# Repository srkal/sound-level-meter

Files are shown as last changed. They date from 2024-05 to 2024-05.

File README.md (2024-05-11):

# sound-level-meter
Sound level meter for workplace with additional features

## Basic Features
* continuous measure of the sound level, use standard decibel scale
* average values from last measures
* display warning when configured level is exceeded
* support IR remote controler for configuration and mode change
* powered by standard type A USB adapter 5V 2A

## Additional Features
* display settings (brightness, rotation, mode) and noise limit are stored to non-volatile flash memory, persist after reboot or power loss
* wifi-manager supported, when connection to last wifi settings fails, switch to Access Point mode and provide interactive web page settings on 192.168.4.1
* automatic time synchronization using Network Time Protocol with correct STD/DST time shifting for central Europe
* periodical check of new firmware versions from server and automatic download and OTA update when found
* when the configured noise level is exceeded, call Google Web-app with current average, chip id, firmware version and local time - will write log entry in Google Sheet

## Used hardware parts
* ESP32 WROOM development module with basic 4MB Flash, without additional PSRAM
* digital MEMS microphone module INMP441 with I2S Interface
* Flexible Led Panel WS2812B RGB matrix 8x8 pixels
* IR receiver VS1838B
* IR Remote Control BN59
* Self locking switch button 8.5 x 8.5 mm (power-on/off)
* Single row pin header strip (module sockets)
* 2 wire red-black cable 20AWG (power supply line)
* Universal double sided PCB board 8x6 cm
* Universal double sided PCB board 8x2 cm
* 6 pin IC socket (for microphone module)
* Type A Male USB 4 Pin Plug Socket Connector With Black Plastic Cover (power supply line)
* Steel Small Phillips Flat Cross Round Head Self-tapping Screw M2
* 10 pin flat color ribbon cable
* Resistor 330 Ohm 0.5W
* Aluminum Electrolytic Capacitor 330uF 6.3V

## Construction
* 3D printed case, base + lid connected together using presision snap joins (open scad files in resources directory)
* hole for power supply line
* PCBs mounted on 3d printed standoffs using screws
* PCBs electrically connected together using flat ribbon cable, soldered, no connectors
* small PCB contains sensors (microphone, IR) and power switch, peeks out through case holes
* large PCB contains microcontroller and other modules
* translucent window made from two layers of transparent foils and lawyer of white paper between foils
* led panel is fixed behind window with hotglue and connected with PCB using 3 pin wire with connector

## Schematics
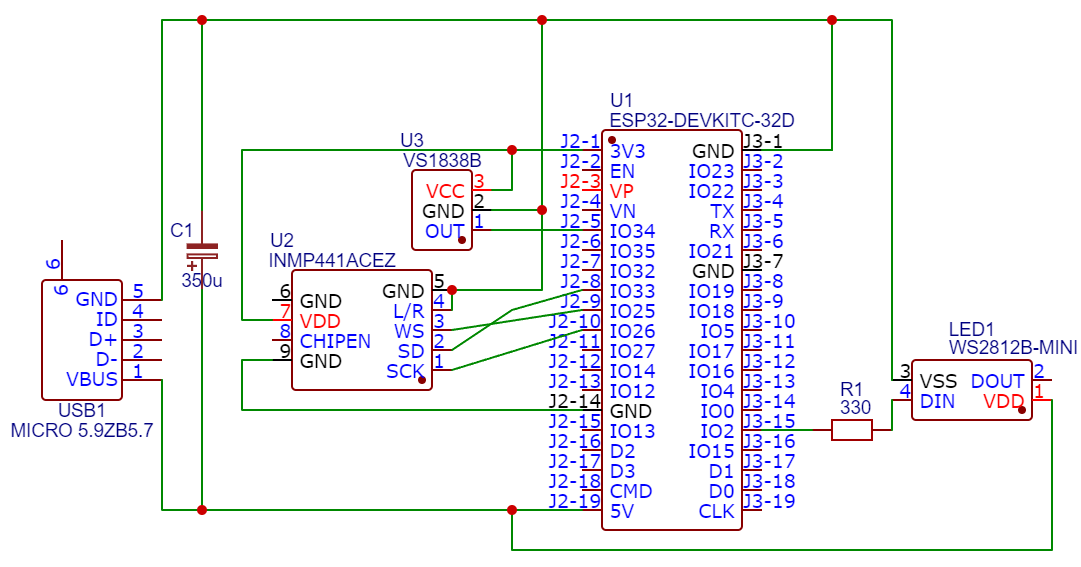
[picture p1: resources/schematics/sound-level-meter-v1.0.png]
schematics


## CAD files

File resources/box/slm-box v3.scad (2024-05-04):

//-----------------------------------------------------------------------
// Yet Another Parameterized Projectbox generator
//
//  This is a box for <template>
//
//  Version 3.0.1 (2024-01-15)
//
// This design is parameterized based on the size of a PCB.
//
// For many/complex cutoutGrills, you might need to adjust
//  the max number of elements in OpenSCAD:
//
//      Preferences->Advanced->Turn off rendering at 250000 elements
//                                                   ^^^^^^
//
//-----------------------------------------------------------------------

include <./YAPPgenerator_v3.scad>

//---------------------------------------------------------
// This design is parameterized based on the size of a PCB.
//---------------------------------------------------------
// Note: length/lengte refers to X axis, 
//       width/breedte refers to Y axis,
//       height/hoogte refers to Z axis

/*
      padding-back|<------pcb length --->|<padding-front
                            RIGHT
        0    X-axis ---> 
        +----------------------------------------+   ---
        |                                        |    ^
        |                                        |   padding-right 
      Y |                                        |    v
      | |    -5,y +----------------------+       |   ---              
 B    a |         | 0,y              x,y |       |     ^              F
 A    x |         |                      |       |     |              R
 C    i |         |                      |       |     | pcb width    O
 K    s |         |                      |       |     |              N
        |         | 0,0              x,0 |       |     v              T
      ^ |    -5,0 +----------------------+       |   ---
      | |                                        |    padding-left
      0 +----------------------------------------+   ---
        0    X-as --->
                          LEFT
*/


//-- which part(s) do you want to print?
printBaseShell        = true;
printLidShell         = true;
printSwitchExtenders  = false;


// ********************************************************************
// The Following will be used as the first element in the pbc array

//Defined here so you can define the "Main" PCB using these if wanted
pcbLength           = 80; // front to back (X axis)
pcbWidth            = 60; // side to side (Y axis)
pcbThickness        = 1.6; 
standoffHeight      = 8.0; //-- How much the PCB needs to be raised from the base to leave room for solderings and whatnot
standoffDiameter    = 7.5;
standoffPinDiameter = 1.7;
standoffHoleSlack   = 0.4;

//===================================================================
// *** PCBs ***
// Printed Circuit Boards
//-------------------------------------------------------------------
//  Default origin =  yappCoordPCB : yappCoordBoxInside[0,0,0]
//
//  Parameters:
//   Required:
//    p(0) = name
//    p(1) = length
//    p(2) = width
//    p(3) = posx
//    p(4) = posy
//    p(5) = Thickness
//    p(6) = standoff_Height
//    p(7) = standoff_Diameter
//    p(8) = standoff_PinDiameter
//   Optional:
//    p(9) = standoff_HoleSlack (default to 0.4)

//The following can be used to get PCB values elsewhere in the script - not in pcb definition. 
//If "PCB Name" is omitted then "Main" is used
//  pcbLength           --> pcbLength("PCB Name")
//  pcbWidth            --> pcbWidth("PCB Name")
//  pcbThickness        --> pcbThickness("PCB Name") 
//  standoffHeight      --> standoffHeight("PCB Name") 
//  standoffDiameter    --> standoffDiameter("PCB Name") 
//  standoffPinDiameter --> standoffPinDiameter("PCB Name") 
//  standoffHoleSlack   --> standoffHoleSlack("PCB Name") 

pcb = 
[
  // Default Main PCB - DO NOT REMOVE the "Main" line.
  ["Main",              pcbLength,pcbWidth,    0,0,    pcbThickness,  standoffHeight, standoffDiameter, standoffPinDiameter, standoffHoleSlack],
    ["Sensors",         80,20,    0,pcbWidth+30,    pcbThickness,  53, standoffDiameter, 2.0, standoffHoleSlack]
];

//-------------------------------------------------------------------                            
//-- padding between pcb and inside wall
paddingFront        = 5;
paddingBack         = 5;
paddingRight        = 5;
paddingLeft         = 5;

//-- Edit these parameters for your own box dimensions
wallThickness       = 3.0;
basePlaneThickness  = 2.0;
lidPlaneThickness   = 2.0;

//-- Total height of box = lidPlaneThickness 
//                       + lidWallHeight 
//--                     + baseWallHeight 
//                       + basePlaneThickness
//-- space between pcb and lidPlane :=
//--      (bottonWallHeight+lidWallHeight) - (standoffHeight+pcbThickness)
baseWallHeight      = 32;
lidWallHeight       = 10;

//-- ridge where base and lid off box can overlap
//-- Make sure this isn't less than lidWallHeight
ridgeHeight         = 6.0;
ridgeSlack          = 0.2;
roundRadius         = 2.0;


// Set the layer height of your printer
printerLayerHeight  = 0.2;


//---------------------------
//--     C O N T R O L     --
//---------------------------
// -- Render --
renderQuality             = 8;          //-> from 1 to 32, Default = 8

// --Preview --
previewQuality            = 5;          //-> from 1 to 32, Default = 5
showSideBySide            = true;       //-> Default = true
onLidGap                  = 0;  // tip don't override to animate the lid opening
colorLid                  = "YellowGreen";   
alphaLid                  = 1;
colorBase                 = "BurlyWood";
alphaBase                 = 1;
hideLidWalls              = true;      //-> Remove the walls from the lid : only if preview and showSideBySide=true 
hideBaseWalls             = false;      //-> Remove the walls from the base : only if preview and showSideBySide=true  
showOrientation           = false;       //-> Show the Front/Back/Left/Right labels : only in preview
showPCB                   = false;      //-> Show the PCB in red : only in preview 
showSwitches              = false;      //-> Show the switches (for pushbuttons) : only in preview 
showButtonsDepressed      = false;      //-> Should the buttons in the Lid On view be in the pressed position
showOriginCoordBox        = false;      //-> Shows red bars representing the origin for yappCoordBox : only in preview 
showOriginCoordBoxInside  = false;      //-> Shows blue bars representing the origin for yappCoordBoxInside : only in preview 
showOriginCoordPCB        = false;      //-> Shows blue bars representing the origin for yappCoordBoxInside : only in preview 
showMarkersPCB            = false;      //-> Shows black bars corners of the PCB : only in preview 
showMarkersCenter         = false;      //-> Shows magenta bars along the centers of all faces  
inspectX                  = 0;          //-> 0=none (>0 from Back)
inspectY                  = 0;          //-> 0=none (>0 from Right)
inspectZ                  = 0;          //-> 0=none (>0 from Bottom)
inspectXfromBack          = true;       //-> View from the inspection cut foreward
inspectYfromLeft          = true;       //-> View from the inspection cut to the right
inspectZfromBottom        = true;       //-> View from the inspection cut up
//---------------------------
//--     C O N T R O L     --
//---------------------------

//-------------------------------------------------------------------
//-------------------------------------------------------------------
// Start of Debugging config (used if not overridden in template)
// ------------------------------------------------------------------
// ------------------------------------------------------------------

//==================================================================
//  *** Shapes ***
//------------------------------------------------------------------
//  There are a view pre defines shapes and masks
//  shapes:
//      shapeIsoTriangle, shapeHexagon, shape6ptStar
//
//  masks:
//      maskHoneycomb, maskHexCircles, maskBars, maskOffsetBars
//
//------------------------------------------------------------------
// Shapes should be defined to fit into a 1x1 box (+/-0.5 in X and Y) - they will 
// be scaled as needed.
// defined as a vector of [x,y] vertices pairs.(min 3 vertices)
// for example a triangle could be [yappPolygonDef,[[-0.5,-0.5],[0,0.5],[0.5,-0.5]]];
// To see how to add your own shapes and mask see the YAPPgenerator program
//------------------------------------------------------------------


// Show sample of a Mask
//SampleMask(maskHoneycomb);
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

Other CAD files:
resources/box/YAPPgenerator_v3.scad

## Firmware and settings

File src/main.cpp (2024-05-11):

#include "MICROPHONE.h"
#include "PANEL.h"
#include "REMOTECONTROL.h"
#include <WiFiManager.h>
#include "NETWORKTIME.h"
PANEL panel = PANEL();
#include "OTAUPDATE.h"

double noise = 0;
WiFiManager wifiManager;

void setup() {
  setCpuFrequencyMhz(160);
  Serial.begin(115200);
  delay(100);
  panel.begin();
  IrReceiver.begin(34, DISABLE_LED_FEEDBACK); // PIN 34 is input only
  samples_queue = xQueueCreate(8, sizeof(sum_queue_t));
  xTaskCreate(mic_i2s_reader_task, "Mic I2S Reader", I2S_TASK_STACK, NULL, I2S_TASK_PRI, NULL);
  wifiManager.setConfigPortalBlocking(false);
  WiFi.setTxPower(WIFI_POWER_8_5dBm);
  wifiManager.autoConnect(); // auto generated AP name from chipid, no password
  ntpInit();
  panel.setNtp(&ntp);
  otaInit();
}

void loop() {
  if (panel.isFirmwareUpdateActive()) {
    return;
  }

  wifiManager.process();
  ntpTimeUpdate();
  otaUpdate();

  if (panel.isAnimationActive()) {
    panel.redraw(noise);
  } else {
    noise = getNoiseValue();
    if (noise > 0.0){ 
      panel.redraw(noise);
    }
  }

  //IR decoder handling
  if (IrReceiver.decode()) {
    //IrReceiver.printIRResultShort(&Serial);
    IrReceiver.resume(); // Enable receiving of the next value

    if (!(IrReceiver.decodedIRData.flags & IRDATA_FLAGS_IS_REPEAT)) {
      if (checkIRCommand(SAMSUNG, IR_SAMSUNG_PRE_CH) || checkIRCommand(NEC, IR_NEC_NUMBER_0)) {
        panel.rotate();
      } else if (checkIRCommand(SAMSUNG, IR_SAMSUNG_NUMBER_1) || checkIRCommand(NEC, IR_NEC_NUMBER_1) || checkIRCommand(NEC, IR_NEC2_NUMBER_1)) {
        panel.setDisplayMode(DISPLAY_MODE_BARS);
      } else if (checkIRCommand(SAMSUNG, IR_SAMSUNG_NUMBER_2) || checkIRCommand(NEC, IR_NEC_NUMBER_2) || checkIRCommand(NEC, IR_NEC2_NUMBER_2)) {
        panel.setDisplayMode(DISPLAY_MODE_NUMBERS);
      } else if (checkIRCommand(SAMSUNG, IR_SAMSUNG_SETTINGS) || checkIRCommand(NEC, IR_NEC_POUND) || checkIRCommand(NEC, IR_NEC2_TIME_SHIFT)) {
        panel.setDisplayMode(DISPLAY_MODE_SETTINGS);  //limit settings
      } else if (checkIRCommand(SAMSUNG, IR_SAMSUNG_CHANNEL_UP) || checkIRCommand(NEC, IR_NEC_UP) || checkIRCommand(NEC, IR_NEC2_CHANNEL_UP)) {
        panel.upBrightness();
      } else if (checkIRCommand(SAMSUNG, IR_SAMSUNG_CHANNEL_DOWN) || checkIRCommand(NEC, IR_NEC_DOWN) || checkIRCommand(NEC, IR_NEC2_CHANNEL_DOWN)) {
        panel.downBrightNess();
      } else if (checkIRCommand(SAMSUNG, IR_SAMSUNG_PRIME_VIDEO) || checkIRCommand(NEC, IR_NEC_STAR)) {
        panel.startAnimation(0, 70, 6);  //test animation
      }

      if (panel.isNoiseLimitActive()) {
        if (checkIRCommand(SAMSUNG, IR_SAMSUNG_ARROW_UP) || checkIRCommand(NEC, IR_NEC_RIGHT) || checkIRCommand(NEC, IR_NEC2_VOLUME_UP)) {
          panel.upNoiseLimit();
        } else if (checkIRCommand(SAMSUNG, IR_SAMSUNG_ARROW_DOWN) || checkIRCommand(NEC, IR_NEC_LEFT) || checkIRCommand(NEC, IR_NEC2_VOLUME_DOWN)) {
          panel.downNoiseLimit();
        }
      }
    }
  }
}
